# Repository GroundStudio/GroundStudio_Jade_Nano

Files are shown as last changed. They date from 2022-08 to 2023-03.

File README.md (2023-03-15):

GroundStudio Jade Nano
====================================
Nano cropat la 150 h (https://ardushop.ro/ro/home/1726-placa-de-dezvoltare-jade-nano.html)

Get it from [ardushop.ro](https://ardushop.ro/ro/home/1726-placa-de-dezvoltare-jade-nano.html)

Explore all the GroundStudio products at [GroundStudio.ro](https://groundstudio.ro/)

Description
-------------------
ATMEGA328P based development board with 32kBytes of In-System Self-Programmable Flash program memory,  1kBytes EEPROM, 2kBytes Internal SRAM, 6 PWM Channels, 20 Digital Pins and 8 channel 10 bit ADC Pins and HT42B534-2 for USB comunication.

Contents
-------------------

* [/Documentation](https://github.com/GroundStudio/GroundStudio_Jade_Nano/tree/main/Documentation/) -- Pinout.
* [/Hardware](https://github.com/GroundStudio/GroundStudio_Jade_Nano/tree/main/Hardware/) -- Schematics, layout.

Versions
-------------------
*(Not all tags shown)*

* [REV0.2]

License
-------------------

This is released under the [Attribution-ShareAlike 4.0 International (CC BY-SA 4.0)](https://creativecommons.org/licenses/by-sa/4.0/) license. 
**You are welcome to use this for commercial purposes.**

Please consider contributing back to this project or others to help the open-source hardware community continue to thrive and grow!

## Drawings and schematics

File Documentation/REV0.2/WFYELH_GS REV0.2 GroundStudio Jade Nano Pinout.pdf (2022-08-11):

# GroundStudio Jade NANO

13

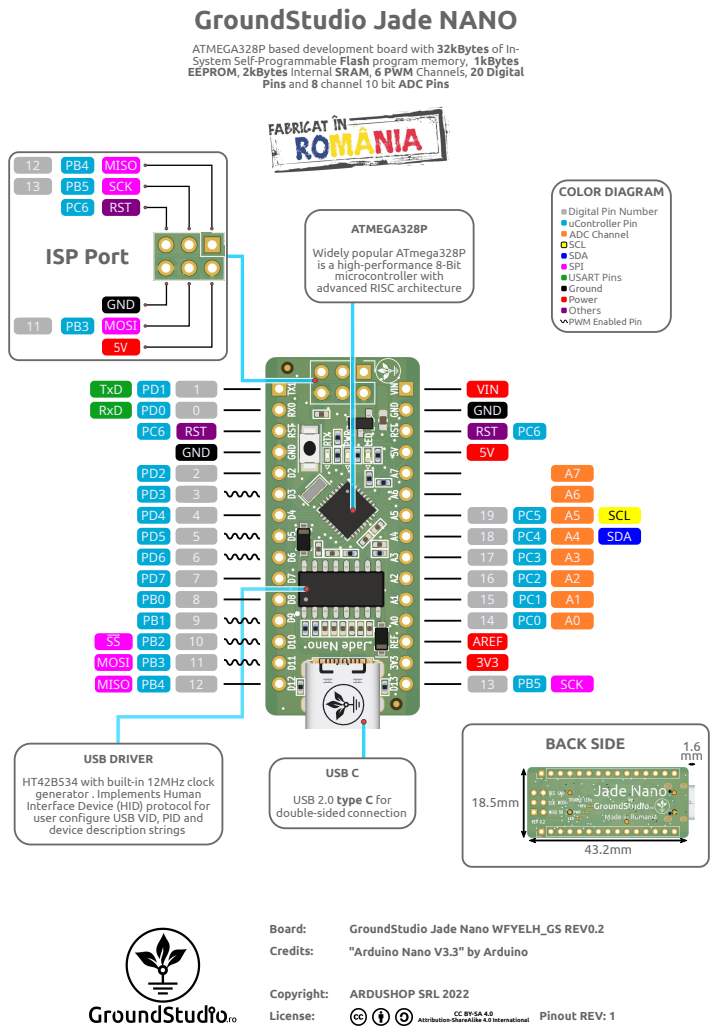
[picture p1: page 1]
SDA; SCL; VIN; GND RST; 17 16 15 14 AREF; PB5 SCK; MISO; MOSI; GND; RST; TxD RxD; BACK SIDE; GND MOSI 5V; SCK; ISP Port; USB DRIVER; USB C; Board:; Credits:; Copyright:; License:; ARDUSHOP SRL 2022; Pinout REV: 1

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

Pins and 8 channel 10 bit ADC Pins

COLOR DIAGRAM
Digital Pin Number
uController Pin
ADC Channel
SCL
SDA
SPI
USART Pins
Ground
Power
Others
PWM Enabled Pin

ATMEGA328P
Widely popular ATmega328P
is a high-performance 8-Bit
microcontroller with
advanced RISC architecture

HT42B534 with built-in 12MHz clock
generator . Implements Human
Interface Device (HID) protocol for
user configure USB VID, PID and
device description strings

USB 2.0 type C for
double-sided connection

GroundStudio Jade Nano WFYELH_GS REV0.2
"Arduino Nano V3.3" by Arduino

Attribution-ShareAlike 4.0 International

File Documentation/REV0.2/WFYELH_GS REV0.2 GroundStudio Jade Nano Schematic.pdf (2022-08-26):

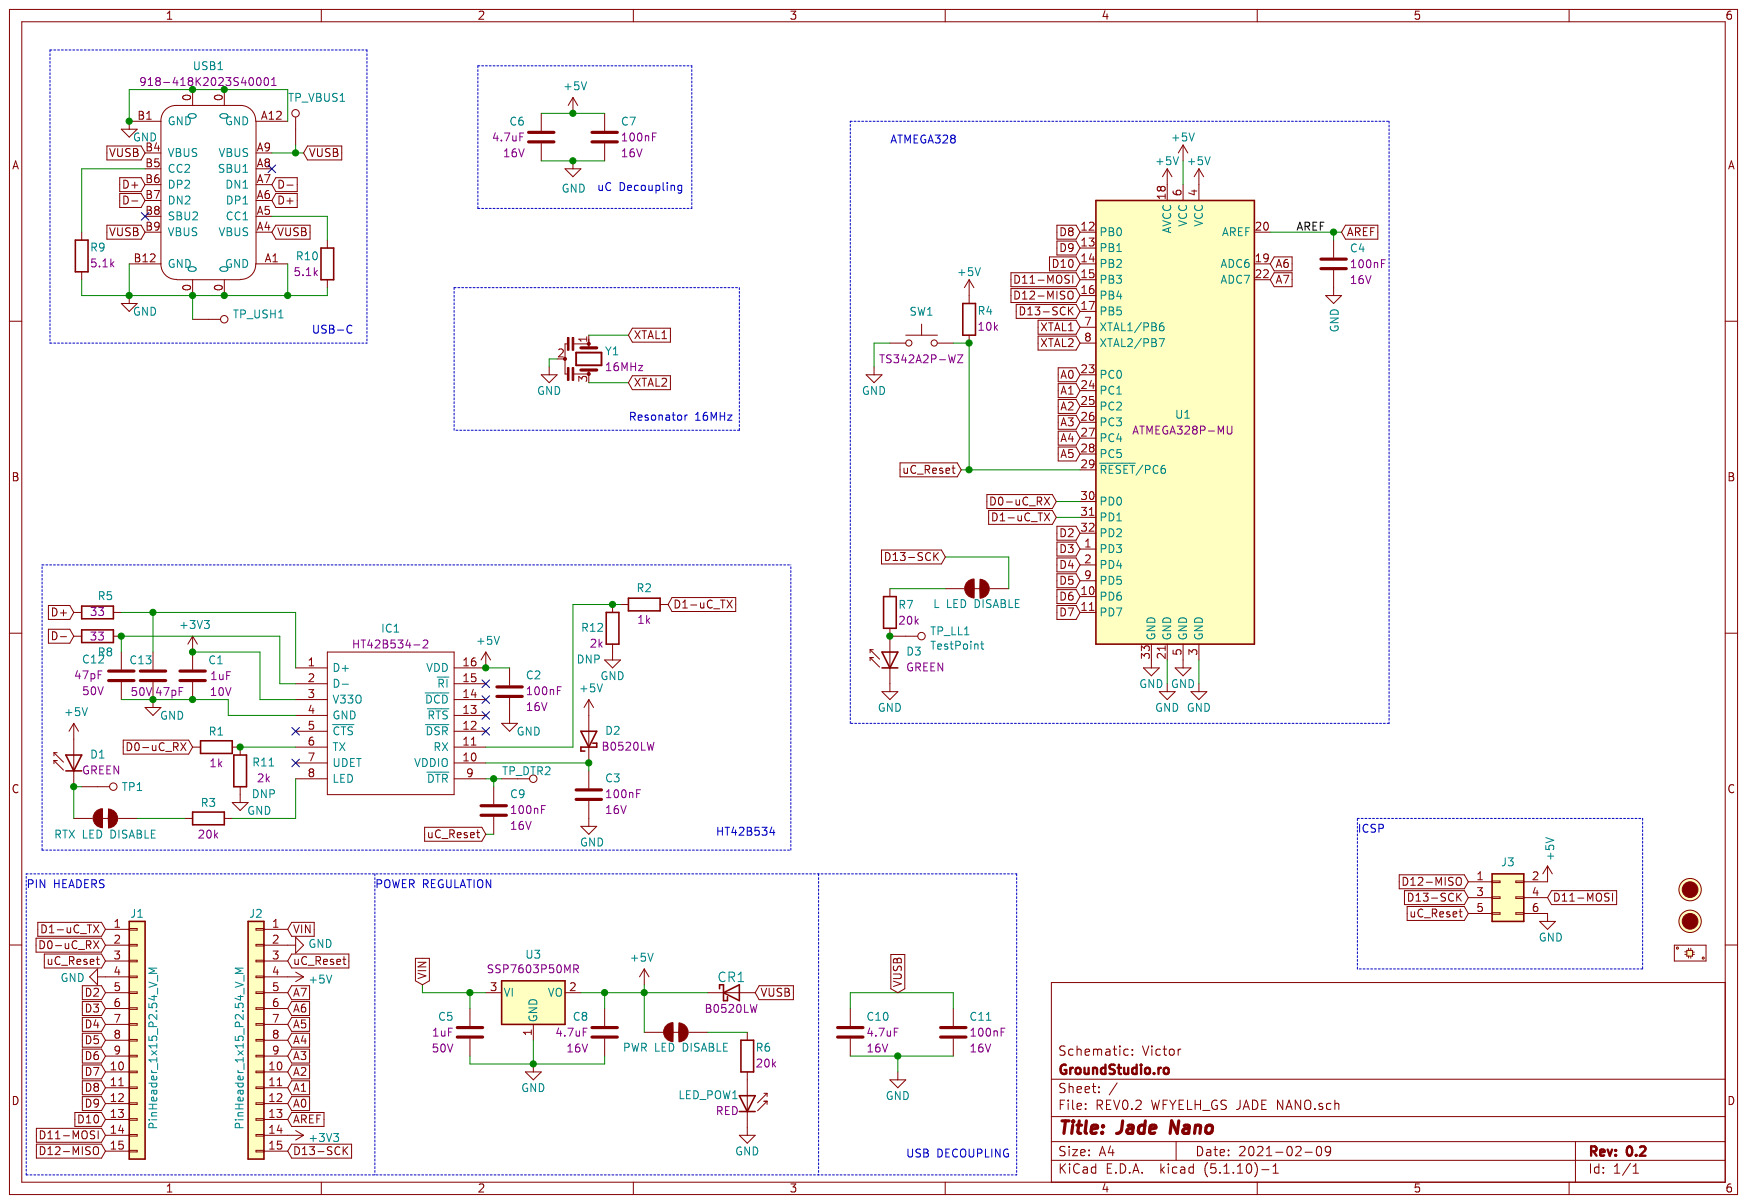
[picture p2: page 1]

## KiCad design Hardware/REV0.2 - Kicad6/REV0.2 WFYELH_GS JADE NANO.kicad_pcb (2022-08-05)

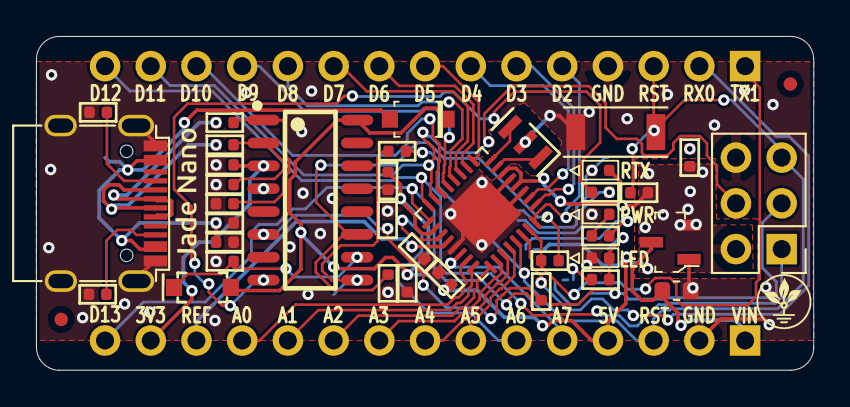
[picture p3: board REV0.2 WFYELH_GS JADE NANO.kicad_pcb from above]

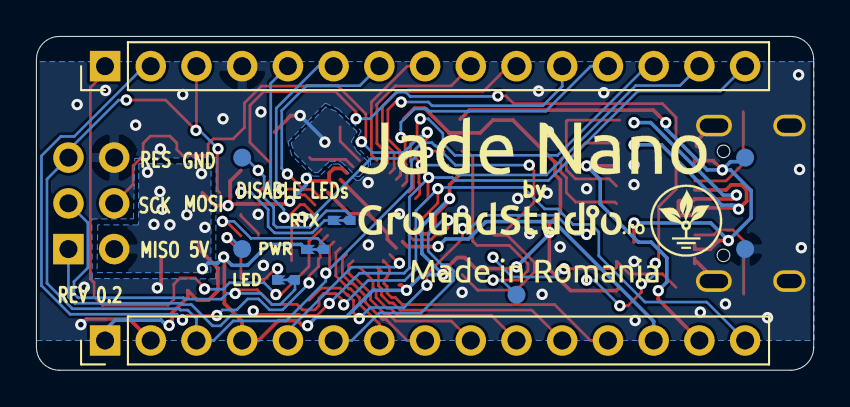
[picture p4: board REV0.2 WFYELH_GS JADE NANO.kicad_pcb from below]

Board: 2 copper layers, 43.2 x 18.5 mm, 49 parts (5 on the bottom side), 48 nets.

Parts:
C1: C_0402_1uF_10V; C_0402_1005Metric
C2, C3, C4, C7, C9, C11: C_0402_100nF_16V; C_0402_1005Metric
C5: C_0603_1uF_50V; C_0603_1608Metric
C6, C8, C10: C_0402_4.7uF_16V; C_0402_1005Metric
C12, C13: C_0402_47pF_50V; C_0402_1005Metric
CR1: SOD-123 B0520LW; SOD-123
D1, D3: LED_0402_GREEN; LED_0402_1005Metric
D2: SOD-123 B0520LW; SOD-123
FID1, FID2: Fiducial; Fiducial_0.75mm_Mask1.5mm
IC1: SOP-16_150MIL HT42B534-2; SOP-16_150MIL
J1, J2: PinHeader_1x15_P2.54_V_M; PinHeader_1x15_P2.54mm_Vertical_Male
J3: PinHeader_2x03_P2.54_V_M; PinHeader_2x03_P2.54mm_Vertical_Male
J4: L LED DISABLE; SolderJumper_NC_small
J5: RTX LED DISABLE; SolderJumper_NC_small
J6: PWR LED DISABLE; SolderJumper_NC_small
LED_POW1: LED_0402_RED; LED_0402_1005Metric
R1, R2: R_0402_1k; R_0402_1005Metric
R3, R6, R7: R_0402_20k; R_0402_1005Metric
R4: R_0402_10k; R_0402_1005Metric
R5, R8: R_0402_33; R_0402_1005Metric
R9, R10: R_0402_5.1k; R_0402_1005Metric
R11, R12: DNP; R_0402_1005Metric
SW1: TS342A2P-WZ
TP1: TestPoint RxTx; TestPoint
TP_DTR2: TestPoint
TP_LL1: TestPoint
TP_USH1: TestPoint
TP_VBUS1: TestPoint
U1: ATmega328P-MU; QFN-32-1EP_5x5mm_P0.5mm_EP3.1x3.1mm
U3: SOT-23-3 SSP7603P50MR; SOT-23-3
USB1: USB_C 918-418K2023S40001; USB_C_C167321
Y1: RSN_3P_3.2x1.3 CSTNE16M0V; CSTNE

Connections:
+3V3: C1.1, IC1.3, J2.14
+5V: C2.2, C6.1, C7.1, C8.1, CR1.1, D1.2, D2.2, IC1.16, J2.4, J3.2, J6.2, R4.2, U1.4, U1.6, U1.18, U3.2
A0: J2.12, U1.23
A1: J2.11, U1.24
A2: J2.10, U1.25
A3: J2.9, U1.26
A4: J2.8, U1.27
A5: J2.7, U1.28
A6: J2.6, U1.19
A7: J2.5, U1.22
AREF: C4.1, J2.13, U1.20
D0-uC_RX: J1.2, R1.2, U1.30
D1-uC_TX: J1.1, R2.2, U1.31
D2: J1.5, U1.32
D3: J1.6, U1.1
D4: J1.7, U1.2
D5: J1.8, U1.9
D6: J1.9, U1.10
D7: J1.10, U1.11
D8: J1.11, U1.12
D9: J1.12, U1.13
D10: J1.13, U1.14
D11-MOSI: J1.14, J3.4, U1.15
D12-MISO: J1.15, J3.1, U1.16
D13-SCK: J2.15, J3.3, J4.1, U1.17
D+: R5.2, USB1.A6, USB1.B6
D-: R8.1, USB1.A7, USB1.B7
GND: C1.2, C2.1, C3.1, C4.2, C5.2, C6.2, C7.2, C8.2, C10.2, C11.2, C12.1, C13.2, D3.1, IC1.4, J1.4, J2.2, J3.6, LED_POW1.1, R9.1, R10.2, R11.1, R12.1, SW1.1, TP_USH1.~, U1.3, U1.5, U1.21, U1.33, U3.1, USB1.0, USB1.A1, USB1.A12, USB1.B1, USB1.B12, Y1.2
unnamed: C3.2, D2.1, IC1.10
unnamed: C9.2, IC1.9, TP_DTR2.~
unnamed: C12.2, IC1.2, R8.2
unnamed: C13.1, IC1.1, R5.1
unnamed: D1.1, J5.1, TP1.~
unnamed: D3.2, R7.2, TP_LL1.~
unnamed: IC1.6, R1.1, R11.2
unnamed: IC1.8, R3.1
unnamed: IC1.11, R2.1, R12.2
unnamed: J4.2, R7.1
unnamed: J5.2, R3.2
unnamed: J6.1, R6.2
unnamed: LED_POW1.2, R6.1
unnamed: R9.2, USB1.B5
unnamed: R10.1, USB1.A5
VIN: C5.1, J2.1, U3.3
VUSB: C10.1, C11.1, CR1.2, TP_VBUS1.~, USB1.A4, USB1.A9, USB1.B4, USB1.B9
XTAL1: U1.7, Y1.1
XTAL2: U1.8, Y1.3
uC_Reset: C9.1, J1.3, J2.3, J3.5, R4.1, SW1.2, U1.29

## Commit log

2022-08-05 -initial commit
    [REV0.2 WFYELH_GS JADE NANO.kicad_pcb, REV0.2 WFYELH_GS JADE NANO.kicad_sch]
2022-08-26 - added schematic pdf file
2022-08-26 - added "Kicad6" to revision folder name
    [REV0.2 WFYELH_GS JADE NANO.kicad_pcb, REV0.2 WFYELH_GS JADE NANO.kicad_sch]
